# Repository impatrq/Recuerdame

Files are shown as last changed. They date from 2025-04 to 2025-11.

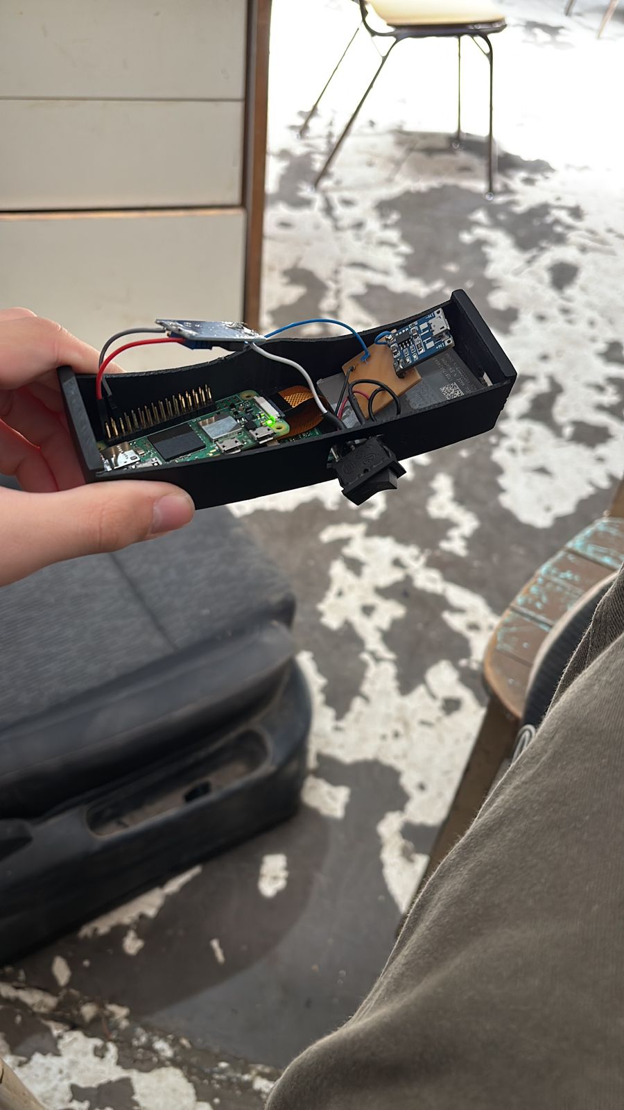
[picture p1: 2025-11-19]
Evidencia de trabajo 2025/Prueba de componentes 3er.jpeg

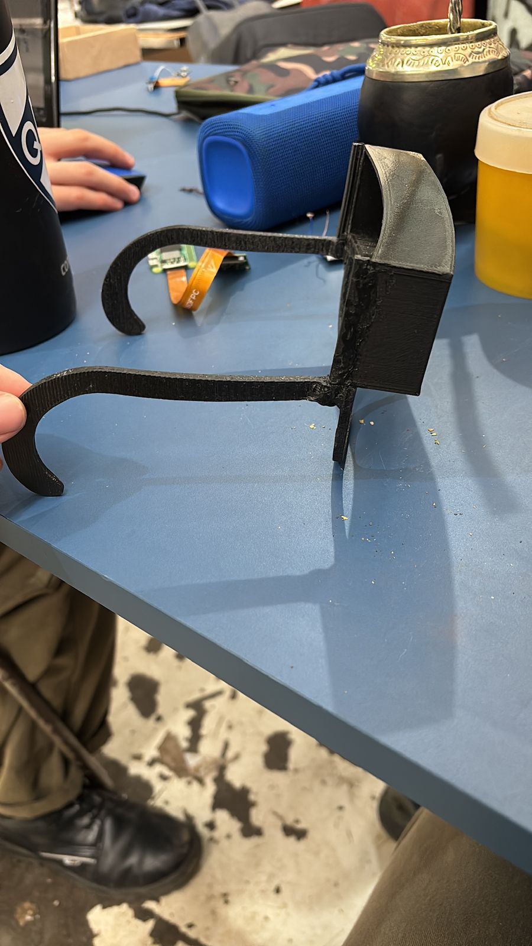
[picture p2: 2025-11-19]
Evidencia de trabajo 2025/Ensamblaje del segundo prototipo.jpeg

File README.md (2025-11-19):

🧠 Recuérdame – Sistema de Asistencia para Personas con Deterioro Cognitivo

Prototipo desarrollado con Raspberry Pi Zero 2, reconocimiento facial y WebApp propia para gestión de pacientes.

⸻

📌 Descripción del Proyecto

Recuérdame es un sistema diseñado para asistir a personas con deterioro cognitivo leve o moderado mediante:
	•	Reconocimiento facial en tiempo real
	•	Identificación por voz
	•	Registro y gestión de personas cercanas (familiares, amigos, cuidadores)
	•	Estadísticas de seguimiento cognitivo

El sistema funciona de manera autónoma, toma fotografías constantemente, detecta rostros y los compara con una base de datos alojada en MongoDB Atlas.
Al encontrar una coincidencia, anuncia por voz:

“Persona reconocida: Juan Pérez. Es su hijo.”

⸻

🚀 Tecnologías Utilizadas

Backend (Running en Raspberry Pi)
	•	Python 3
	•	Librería face_recognition
	•	PIL (Pillow)
	•	MongoDB Atlas mediante pymongo
	•	rpicam-apps (rpicam-still)
	•	espeak (síntesis de voz)

Frontend / WebApp
	•	HTML, CSS y JavaScript
	•	Express.js para servir la app
	•	MongoDB Atlas para almacenar pacientes
	•	Diseño mobile-first y estilo de app nativa

⸻

🧩 Cómo Funciona el Sistema
	1.	Los lentes capturan fotos cada 1 segundo.
	2.	El sistema detecta si hay un rostro presente.
	3.	Si se detecta una cara:
	•	Se genera su encoding (vector facial).
	•	Se compara con las codificaciones de la base de datos.
	4.	Si coincide con alguien registrado:
	•	Informa nombre y relación por voz.
	5.	Todo funciona de manera local, sin internet, una vez cargada la base.

⸻

📦 Instalación

1. Clonar el repositorio

		git clone https://github.com/tuusuario/Recuerdame.git
		cd Recuerdame

2. Instalar dependencias de Python

		pip install face_recognition pymongo pillow numpy

3. Instalar rpicam-apps

		sudo apt install rpicam-apps

4. Instalar espeak

		sudo apt install espeak

5. Configurar tu string de MongoDB en el archivo Python

		MONGODB_URI = "mongodb+srv://..."

⸻

▶️ Cómo Usar Recuérdame

1. Conectar el dispositivo a una red WiFi

2. Acceder a la terminal sin cable USB

(Gracias al sistema interno de acceso remoto)

3. Iniciar sesión con usuario y contraseña del equipo

4. Obtener la IP local

	hostname -I

5. En el navegador (misma red), entrar a la WebApp

	http://IP:5000

Ejemplo:

	192.168.0.15:5000

6. Registrar personas

En la sección Personas, se cargan:
	•	Nombre
	•	Relación
	•	Foto

Luego reiniciar Recuérdame para actualizar encodings.

7. Funcionamiento autónomo

Al iniciar:
	•	Procesa las fotos
	•	Crea las codificaciones
	•	Anuncia:
“Sistema Recuérdame listo para ayudarte.”
	•	Comienza a reconocer personas automáticamente.

8. Batería
	•	Carga por Micro-USB
	•	Aproximadamente 1 hora de carga = 3 horas de autonomía

⸻

📊 Estadísticas del Paciente

La WebApp calcula automáticamente:
	•	Cantidad de preguntas correctas / incorrectas / omitidas
	•	Último test realizado
	•	Tendencias semanales/mensuales
	•	Caídas significativas en orientación temporal o memoria
	•	Alertas visuales a familiares o profesionales

Incluye también una ficha rápida del paciente en la pantalla principal.
⸻

🔧 Arquitectura General

	[ Cámara Raspberry ] -> captura -> [ Procesador Pi Zero 2 ]
	        |                                     |
	        v                                     v
	[ face_recognition ] -> encodings -> [ Comparación con DB ]
	        |                                     |
	        v                                     v
	[ Identificación ] -----------------> [ Síntesis de voz ESpeak ]
	
⸻

🤝 Agradecimientos / Sponsors
	•	FADESA – Financió el 100% del proyecto.
	•	Proyecto Color – Diseño e impresión 3D de piezas.
	•	UADE – Prestó laboratorios y equipamiento.

⸻

🧑‍💻 Autores

    Carlos Gabri Krizak 
    Facundo Mendez
    Pedro Amenta

⸻

🏁 Estado del Proyecto

✔️ Prototipo funcional
✔️ Reconocimiento con ~80% de precisión
✔️ Base de datos integrada
✔️ WebApp operativa
⚙️ Mejoras futuras: optimizar rendimiento, integrar batería más grande.

⸻

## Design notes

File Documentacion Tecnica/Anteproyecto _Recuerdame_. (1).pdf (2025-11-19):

Escuela de Educación Técnica Nº7
Taller Regional Quilmes
Prácticas Profesionalizantes: Especialidad Aviónica

# Recuérdame

## Presentación de anteproyecto

### Recuerdame:

El nombre "Recuérdame" surge como una referencia directa a la función principal del proyecto: ayudar a personas con Alzheimer a recordar a sus seres queridos. Además, su fácil pronunciación y significado emotivo permiten una conexión inmediata con su propósito.

### Integrantes:

- AMENTA, Pedro.
- MENDEZ, Facundo.
- GABRI KRIZAK, Carlos.

### Objetivo del proyecto:

El objetivo de este proyecto es desarrollar unos lentes inteligentes diseñados para asistir a personas con la enfermedad de Alzheimer y a sus familiares o acompañantes en el proceso de afrontarla. Estos lentes incorporarán tecnología de reconocimiento facial y un sistema de audio que informará al usuario sobre la identidad y el parentesco de las personas a su alrededor.

Además, contarán con una funcionalidad interactiva que permitirá realizar preguntas diseñadas para ejercitar la capacidad cognitiva del paciente, como: "¿Cómo se llama su hijo?", "¿Tiene hijos?", "¿Cuántos?" o "¿Cuál era el nombre de sus padres?". Este método, altamente recomendado por profesionales, ayuda a estimular la memoria y reforzar la conexión con sus recuerdos.

Para evaluar la evolución del paciente, las respuestas a estas preguntas se registran y se convertirán en estadísticas visualizadas en gráficos dentro de la aplicación móvil. A través de esta app, los familiares y cuidadores podrán hacer un seguimiento del estado cognitivo del usuario y detectar posibles cambios en su capacidad de recordar información con el tiempo.

La finalidad de este proyecto es mejorar la calidad de vida de los pacientes, promover su autonomía y facilitar la comunicación con sus familiares y cuidadores, brindando una herramienta tecnológica accesible y eficaz.

### Utilidades de el proyecto:

El proyecto beneficiará directamente a pacientes con Alzheimer y a sus familiares, quienes podrán mantener una comunicación más efectiva y reducir la angustia generada por el desconocimiento. También podría ser de interés para centros de salud y organizaciones dedicadas a la atención de adultos mayores, mejorando la asistencia a personas con deterioro cognitivo.

### Descripción del funcionamiento:

Los lentes capturan la imagen de una persona mediante una cámara integrada. Esta imagen se envía a una Raspberry Pi Zero 2, donde se procesa con un sistema de reconocimiento facial. Si la persona es identificada en la base de datos, el sistema emite un mensaje de audio con su nombre y relación con el usuario.

Además de esta función principal, los lentes están diseñados para ayudar a estimular la memoria del paciente a través de preguntas interactivas. Estas preguntas pueden incluir: "¿Cómo se llama su hijo?", "¿Tiene hijos?", "¿Cuántos?", o "¿Cuál era el nombre de sus padres?". Este enfoque está respaldado por profesionales en el área de la salud, quienes recomiendan este tipo de ejercicios para mantener activa la capacidad cognitiva del usuario.

La interacción con el sistema se realizará mediante una aplicación vinculada, que permitirá ajustar parámetros como el volumen del audio, la frecuencia de las preguntas y la gestión de la base de datos de contactos. A largo plazo, se prevé la integración de tecnologías adicionales para mejorar la experiencia del usuario y optimizar el rendimiento del dispositivo.

### Análisis de factibilidad:

- Pedro Amenta: Redes sociales, diseño del logotipo, contacto con Sponsors, Encargado de Anteproyecto, investigación sobre la enfermedad.
- Problemática a resolver: Deberá definir una estrategia de marketing efectiva para aumentar la visibilidad del proyecto y atraer patrocinadores, garantizando que el mensaje llegue a las personas y organizaciones adecuadas.
- Segunda problemática a resolver: Tendrá que hacer un mensaje claro, conciso y convincente para la comunicación con marcas que puedan sponsorear distintas partes de nuestro proyecto.
- Tercera problemática a resolver: Será necesario capacitarse sobre la enfermedad de Alzheimer para adaptar el proyecto de la mejor manera posible a la vida de las personas que la padecen, garantizando que cuenten con todas las herramientas necesarias para mejorar su autonomía y calidad de vida.
- Carlos Gabri Krizak: Investigacion y Planificacion del proyecto, Desarrollo de App, Desarrollo del reconocimiento facial
- Problemática a resolver: Implementar un sistema de reconocimiento facial eficiente y de bajo consumo en la Raspberry Pi Zero 2, asegurando que funcione correctamente en distintas condiciones de iluminación y con diferentes ángulos de los rostros.

- Segunda problemática a resolver: Junto a su otro compañero hacer una capacitación y aumentar su conocimiento sobre la creación y desarrollo de aplicaciones.
- Facundo Mendez : Diseño de los lentes, Desarrollo de App
- Primera problemática a resolver: Diseñar un armazón de lentes ergonómico que pueda albergar los componentes electrónicos sin afectar la comodidad del usuario, garantizando al mismo tiempo que los sensores y la cámara funcionen correctamente.
- Segunda problemática a resolver: Junto a su otro compañero hacer una capacitación y aumentar su conocimiento sobre la creación y desarrollo de aplicaciones.

### Costo del proyecto:

- Raspberry Pi Zero 2: $34.000
- Cámara Módulo Raspberry CAM V1.3: $10.000
- Batería LiPo 1000mAh: $21.989

COSTO TOTAL ESTIPULADO: $65.989

### Análisis de costo/beneficio:

El costo de los componentes es relativamente accesible en comparación con el impacto positivo que puede generar el proyecto en la vida de los pacientes con Alzheimer y sus familias. Al ofrecer una solución tecnológica innovadora, se justifica la inversión en el desarrollo del prototipo, con posibilidades de financiamiento a través de entidades de salud o apoyo gubernamental.

Comparativa de soluciones a problemas actuales con soluciones que traería “Recuerdame”:

- Dificultad para reconocer a familiares y amigos debido al Alzheimer.
- Soluciones Actuales: Los cuidadores o familiares deben recordarles constantemente quiénes son las personas a su alrededor, lo que puede ser frustrante y no siempre efectivo. (Prácticamente no es una solución)
- Cómo lo resolvería "Recuérdame": Mediante el reconocimiento facial, los lentes identifican a las personas cercanas y proporcionan al usuario información auditiva sobre su identidad y parentesco.
- Pérdida de autonomía del paciente.
- Soluciones Actuales: Los pacientes suelen depender completamente de cuidadores para orientarse en su entorno social.
- Cómo lo resolvería "Recuérdame": Nuestro proyecto permite que los pacientes puedan interactuar de forma más independiente al recibir información sobre quienes los rodean sin necesidad de preguntar.
- Falta de estimulación cognitiva efectiva.
- Soluciones Actuales: Se utilizan ejercicios de memoria en papel o aplicaciones móviles que requieren que el usuario interactúe activamente con una pantalla.
- Cómo lo resolvería "Recuérdame": Los lentes integran un sistema de preguntas auditivas automatizadas para reforzar la memoria del paciente de manera más accesible y sin necesidad de manipular dispositivos.
- Falta de soluciones tecnológicas accesibles para pacientes con Alzheimer.
- Soluciones Actuales: Existen algunas apps de recordatorio, pero no hay dispositivos portátiles diseñados específicamente para asistir en tiempo real.
- Cómo lo resolvería "Recuérdame": Nuestro proyecto es un dispositivo wearable que proporciona ayuda en tiempo real sin necesidad de interacción manual.

### Diagrama en bloques del prototipo:

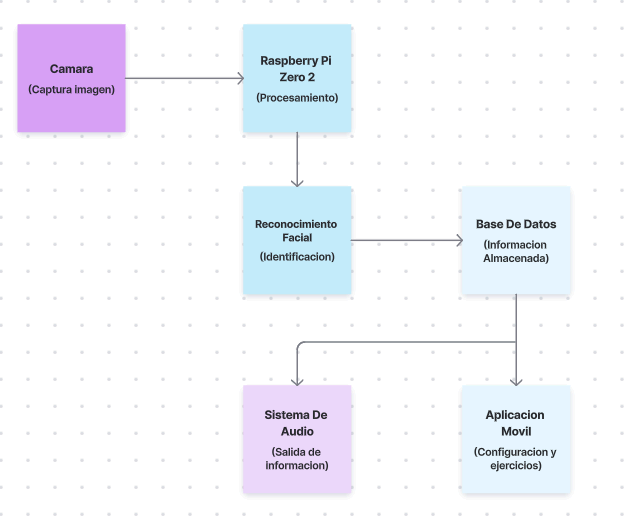
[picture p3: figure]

### Diagrama de tiempo de desarrollo:

- Etapa 1: Investigación y planificación (2 semanas, en proceso)
- Etapa 2: Marketing y propaganda (Tiempo indefinido, en proceso)
- Etapa 3: Desarrollo del sistema de reconocimiento facial (6 semanas)
- Etapa 4: Desarrollo de la aplicación móvil (6 semanas)
- Etapa 5: Diseño de los lentes (4 semanas)
- Etapa 6: Integración del sistema en los lentes (4 semanas)
- Etapa 7: Pruebas y ajustes finales (Tiempo indefinido)

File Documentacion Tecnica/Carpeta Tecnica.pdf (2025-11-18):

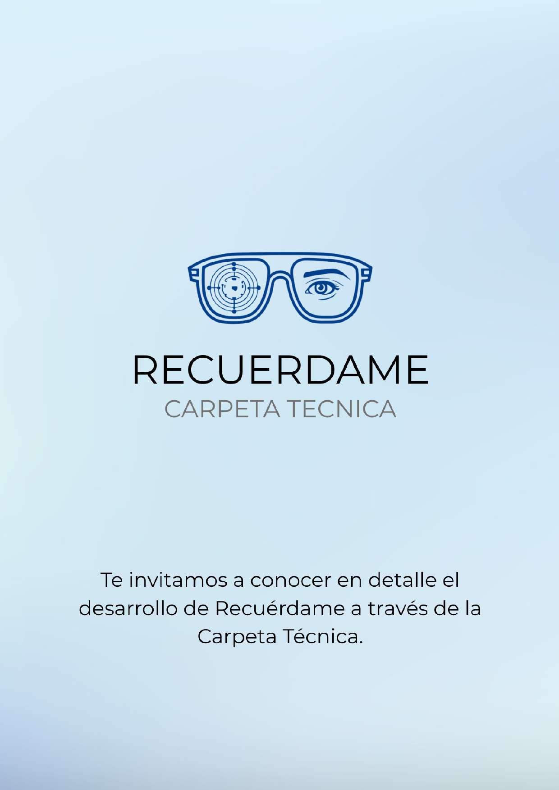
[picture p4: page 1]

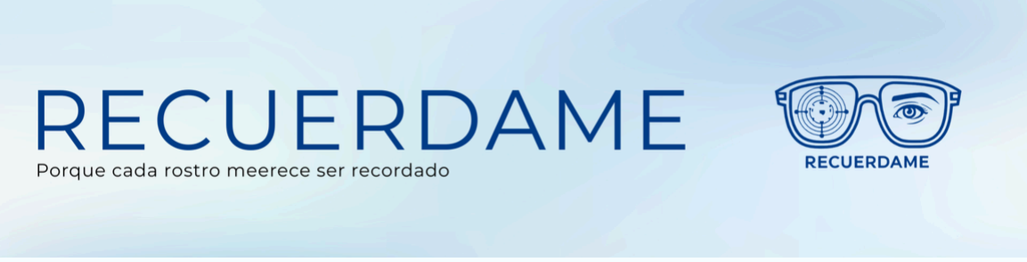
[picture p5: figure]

# Carpeta Técnica – Proyecto Recuérdame

1. ¿Qué es Recuérdame?
2. ¿Cómo Nace Recuérdame?
3. Objetivos
a. Objetivo general
b. Objetivos específicos
4. Hardware
a. Componentes utilizados
b. Modelo 3D y Estructura
5. Software
a. Sistema de reconocimiento facial (lentes inteligentes)
b. WebApp “Recuérdame App”
c. Pagina Web informativa
6. Resultados y pruebas
a. Pruebas del sistema de reconocimiento facial
b. Pruebas de conexión con la base de datos y la WebApp
c. Resultados generales
7. Agradecimientos
8. Conclusión

## ¿Qué es “Recuérdame”?

Recuérdame es un sistema de asistencia inteligente diseñado para ayudar a personas con pérdida de memoria o dificultades cognitivas.
El proyecto combina hardware y software para reconocer rostros y brindar información relevante sobre las personas que el usuario ve, ayudándolo a mantener su autonomía y mejorar su calidad de vida.

El sistema está compuesto por unos lentes inteligentes, desarrollados con una Raspberry Pi Zero 2, una cámara y un módulo de audio Bluetooth, que permiten capturar imágenes del entorno y procesarlas mediante reconocimiento facial.

Además, cuenta con una WebApp, donde familiares o profesionales pueden registrar personas, realizar preguntas cognitivas diarias y monitorear el estado cognitivo del paciente a través de estadísticas automáticas.

El objetivo principal de Recuérdame es ofrecer una herramienta accesible y práctica para acompañar a quienes padecen enfermedades neurodegenerativas como el Alzheimer, combinando tecnología e inclusión social.

## ¿Cómo nace Recuérdame?

El proyecto Recuérdame nació a partir de una experiencia personal de uno de los integrantes. A comienzos del año, mientras Carlos hablaba con su papá sobre su bisabuela (quien padecía demencia) recordó cómo, en un mismo día, le preguntaba varias veces “¿Quién sos vos?”. Cada vez que el le respondía, ella le contestaba “Ya sabía, te estaba cargando”, intentando disimular la vergüenza que le generaba no recordar.

Esa situación lo marcó profundamente y lo hizo pensar en lo difícil que debe ser convivir con la pérdida de la memoria, tanto para quien la sufre como para sus familiares y acompañantes. Recuérdame nace de ese recuerdo, con la idea de crear una herramienta que brinde apoyo y contención mediante la tecnología.

## Objetivos

### Objetivo general

Desarrollar un sistema de lentes inteligentes capaz de asistir a personas con pérdida de memoria mediante el reconocimiento facial y una plataforma web de seguimiento cognitivo, promoviendo la autonomía, la seguridad y el bienestar del usuario.

### Objetivos específicos

Implementar un sistema de reconocimiento facial utilizando la cámara de la Raspberry Pi Zero 2.

Diseñar y fabricar una estructura ergonómica mediante modelos 3D para integrar los componentes electrónicos en unos lentes funcionales.
Desarrollar una WebApp que permita registrar personas, realizar preguntas cognitivas diarias y almacenar resultados en una base de datos.
Establecer una comunicación entre los lentes y la aplicación para el intercambio de información (alertas, estadísticas, etc.).
Generar estadísticas automáticas que evalúen el rendimiento cognitivo para el médico de cabecera.
Garantizar que el sistema sea accesible, intuitivo y adaptable a las necesidades de cada usuario.

## Hardware

### Componentes utilizados

El sistema Recuérdame está construido a partir de distintos módulos electrónicos que trabajan en conjunto para permitir el reconocimiento facial y la comunicación con la aplicación.
A continuación, se detallan los principales componentes utilizados:

Raspberry Pi Zero 2 W: microcomputadora principal encargada del procesamiento, reconocimiento facial y de ejecutar la App.
Cámara para Raspberry Pi: permite capturar imágenes del entorno para realizar el reconocimiento de rostros.
Módulo TP4056: utilizado para la carga de la batería de litio, brindando protección contra sobrecarga y sobredescarga.
Step-up booster (DC-DC): eleva el voltaje de la batería (3.7 V) a 5 V, necesarios para alimentar la Raspberry Pi.
Batería recargable de litio: fuente de energía principal de los lentes.
Cableado y conectores: empleados para interconectar los distintos módulos de manera segura y compacta.

Conexiones: todos los componentes fueron integrados mediante soldaduras y cables flexibles para minimizar el espacio ocupado dentro de la estructura de los lentes.

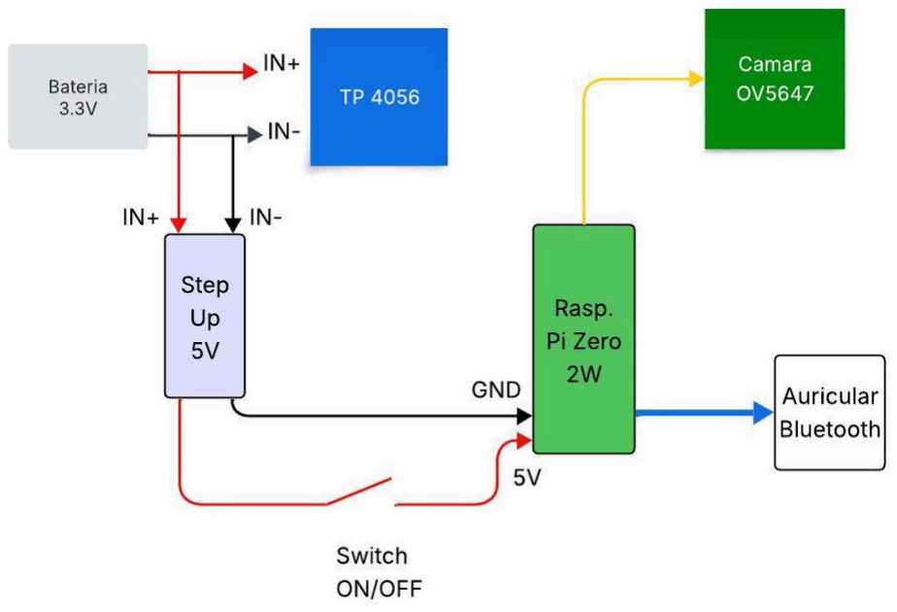
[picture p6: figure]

### Modelos 3D y estructura

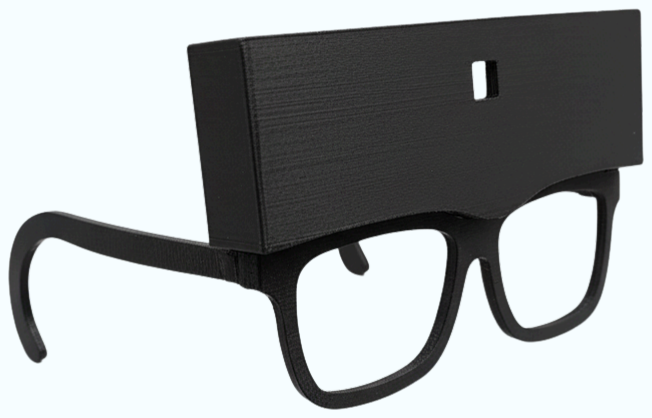
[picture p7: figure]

Para integrar todos los componentes, se diseñó un modelo 3D de los lentes inteligentes, adaptado para alojar la Raspberry Pi, la cámara y los módulos electrónicos sin afectar la comodidad del usuario.

El diseño fue realizado con software de modelado 3D (AutoCAD) y luego impreso con impresora 3D utilizando material PLA.
El objetivo del diseño fue lograr una estructura ergonómica, liviana y estética, que permita el uso prolongado sin incomodidad, manteniendo la funcionalidad del sistema.

## Software

El software de Recuérdame integra distintos componentes que trabajan en conjunto para conectar los lentes inteligentes con la WebApp de seguimiento cognitivo.
El sistema fue desarrollado para funcionar en un entorno de bajo consumo de recursos, utilizando modelos preentrenados optimizados para la Raspberry Pi Zero 2, y una arquitectura cliente-servidor que permite la comunicación entre el hardware y la base de datos en la nube.

### Sistema de reconocimiento facial (lentes inteligentes)

Debido a las limitaciones de hardware de la Raspberry Pi Zero 2, se optó por no utilizar librerías pesadas como OpenCV.
En su lugar, el reconocimiento facial se basa en tres modelos preentrenados livianos, cada uno con una tarea específica:

Modelo de detección de rostros: identifica la posición de las caras dentro del fotograma. Modelo de reconocimiento facial: obtiene los rasgos característicos (embeddings) de cada rostro detectado.
Modelo de comparación: compara los embeddings del rostro actual con los almacenados en la base de datos local o remota, determinando si corresponde a una persona conocida.

### WebApp “Recuérdame App”

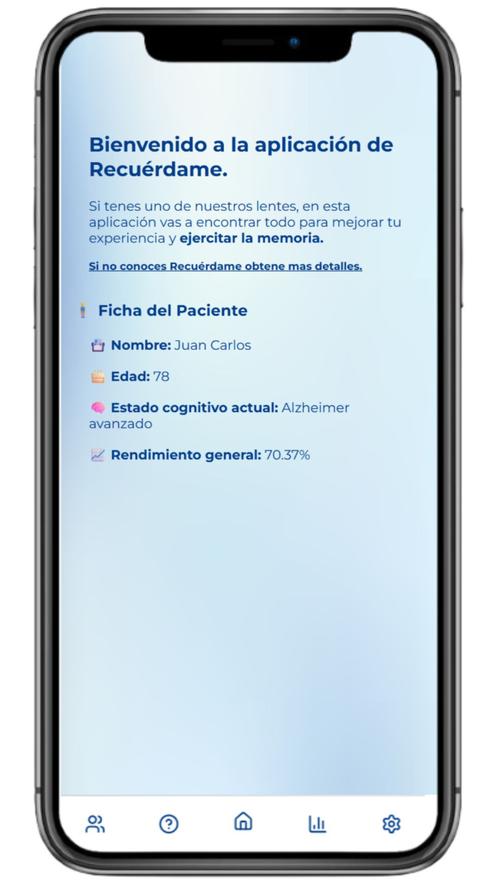
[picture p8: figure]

La WebApp fue desarrollada desde cero con el objetivo de ofrecer una interfaz intuitiva y moderna, optimizada para dispositivos móviles.
Está implementada con las siguientes tecnologías:

Frontend: HTML, CSS y JavaScript (con diseño tipo app nativa).
Backend: Node.js con Express.
Base de datos: MongoDB Atlas. Servidor: ejecutado en el puerto 5000, sirviendo contenido estático desde la
carpeta public.

La aplicación permite a familiares o profesionales:

Registrar personas, asociarles fotos y descripciones.
Realizar preguntas cognitivas diarias, clasificadas por tipo (memoria, orientación temporal, orientación espacial, lenguaje y cálculo).
Registrar las respuestas como “Correcta” o “Incorrecta”.
Generar estadísticas automáticas semanales y mensuales, mostrando patrones de rendimiento.
Alertar automáticamente si se detecta una baja significativa en el rendimiento del paciente.

### Interfaz del usuario en la App

La WebApp cuenta con una interfaz de navegación simple, pensada para adultos mayores y cuidadores.
Las principales vistas son:

Pantalla de inicio: muestra la ficha rápida del paciente (nombre, edad, estado cognitivo, último test y rendimiento general).
Vista Personas: lista de personas registradas con opción para agregar, editar o eliminar. Vista Preguntas: donde se realizan las preguntas cognitivas diarias.
Vista Estadísticas: presenta gráficos del progreso y alertas automáticas sobre posibles deterioros.

### Página web informativa

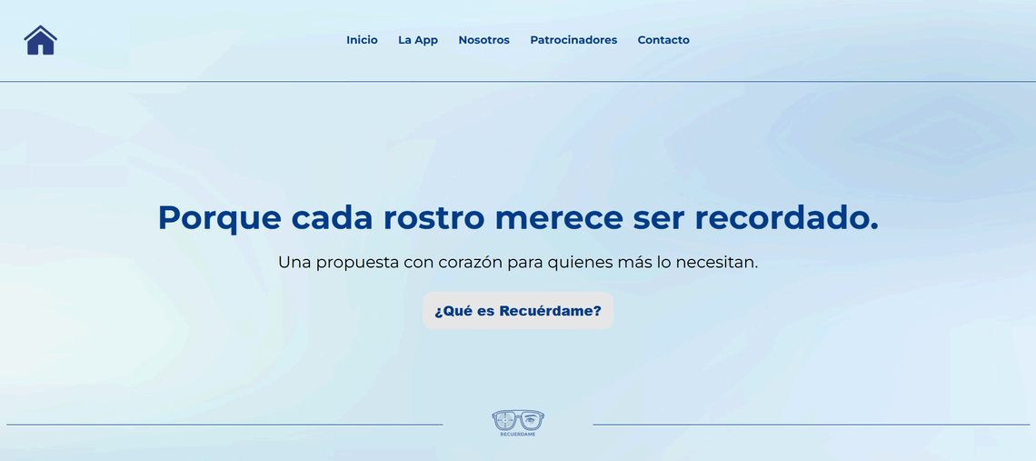
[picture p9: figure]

El proyecto cuenta con una página web informativa alojada en el dominio propio https://recuerdamecpf.lat. (https://recuerdamecpf.lat/?utm_source=chatgpt.com)
Fue desarrollada por el grupo utilizando HTML, CSS y JavaScript, con un diseño moderno, simple y adaptable a distintos dispositivos.

La web tiene como objetivo presentar el proyecto, explicar su funcionamiento de forma general y mostrar información sobre el equipo desarrollador.
Su función principal es divulgar y representar al proyecto en la muestra escolar y en eventos, sirviendo como carta de presentación digital.

## Resultados y pruebas

### Pruebas del sistema de reconocimiento facial

El sistema de reconocimiento fue probado con los tres integrantes del equipo de desarrollo, utilizando los modelos preentrenados de detección, reconocimiento y comparación facial. Durante las pruebas, el sistema logró identificar correctamente los rostros en aproximadamente un 80 % de los intentos, mostrando un buen nivel de precisión considerando las limitaciones de hardware de la Raspberry Pi Zero 2.

El funcionamiento es autónomo, sin necesidad de conexión a una computadora externa, lo cual demuestra la viabilidad del diseño para su uso independiente en los lentes inteligentes.

### Pruebas de conexión con la base de datos y la WebApp

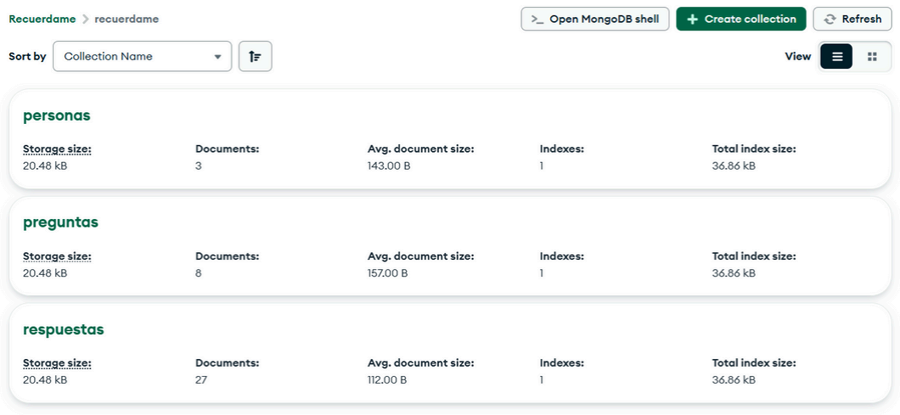
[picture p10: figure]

Se realizaron pruebas exitosas de conexión con la base de datos MongoDB Atlas, verificando el correcto envío, almacenamiento y lectura de datos a través del servidor Node.js / Express.
La WebApp permitió registrar usuarios, responder preguntas cognitivas y visualizar los resultados en tiempo real, confirmando el correcto funcionamiento del flujo completo de datos entre el dispositivo, el servidor y la base
de datos.

### Resultados generales

En conjunto, las pruebas realizadas demostraron que el sistema es funcional, estable y cumple con los objetivos propuestos:

Detecta y reconoce rostros de manera autónoma.
Se comunica correctamente con la base de datos.
Presenta una interfaz web informativa y una WebApp funcional.

## Agradecimientos

Queremos agradecer a las instituciones y organizaciones que hicieron posible el desarrollo de Recuérdame:

FADESA (Fundación Argentina para el Desarrollo de la Salud), por financiar el 100 % del proyecto y confiar en nuestra propuesta desde el inicio.
Proyecto Color, por su colaboración en el diseño y la impresión de las piezas en 3D, aportando precisión y calidad al prototipo final.
UADE (Universidad Argentina de la Empresa), por su buena predisposición y por permitirnos utilizar sus laboratorios para realizar pruebas y ensayos del sistema.

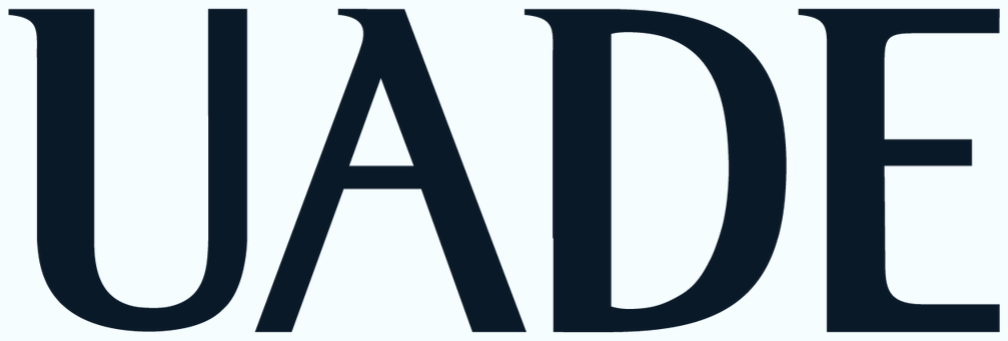
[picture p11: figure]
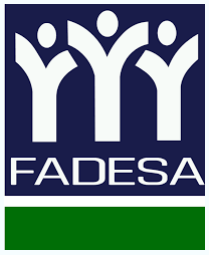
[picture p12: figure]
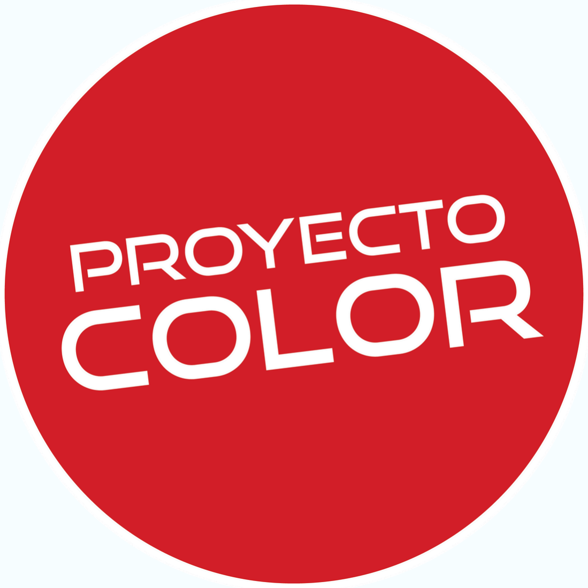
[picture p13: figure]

## Conclusión

El desarrollo de Recuérdame permitió aplicar conocimientos de electrónica, programación y diseño 3D en un proyecto con impacto social real.
El sistema logró cumplir con los objetivos propuestos, demostrando que es posible integrar hardware de bajo costo para mejorar la calidad de vida de las personas con pérdida de memoria.

El trabajo reflejó el esfuerzo y compromiso del grupo en todas sus etapas (desde la idea inicial hasta las pruebas finales), combinando innovación tecnológica y empatía humana.

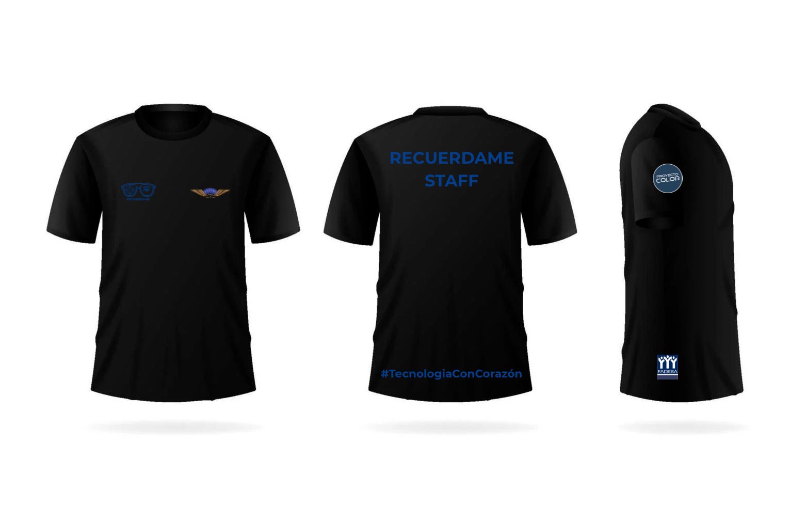
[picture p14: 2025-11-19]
Evidencia de trabajo 2025/Diseño Remeras.jpeg

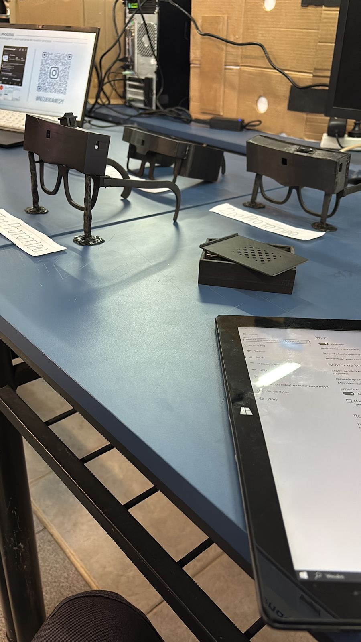
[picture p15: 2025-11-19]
Evidencia de trabajo 2025/Stand Oniet.jpeg

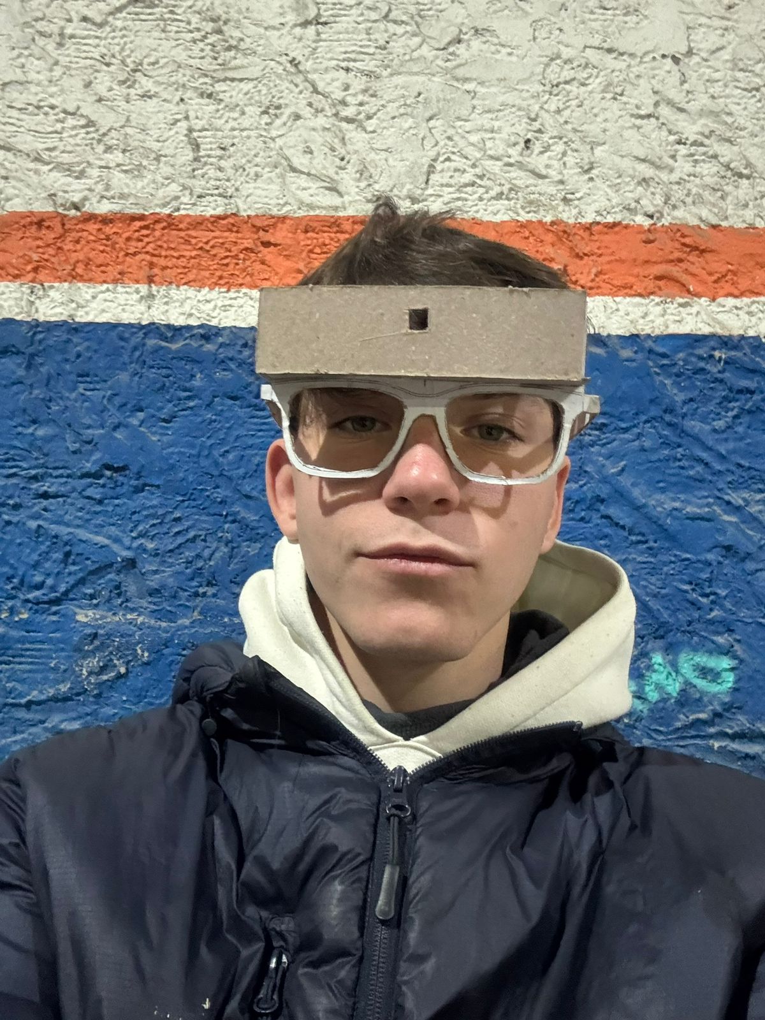
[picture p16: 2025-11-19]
Evidencia de trabajo 2025/Carton.jpeg

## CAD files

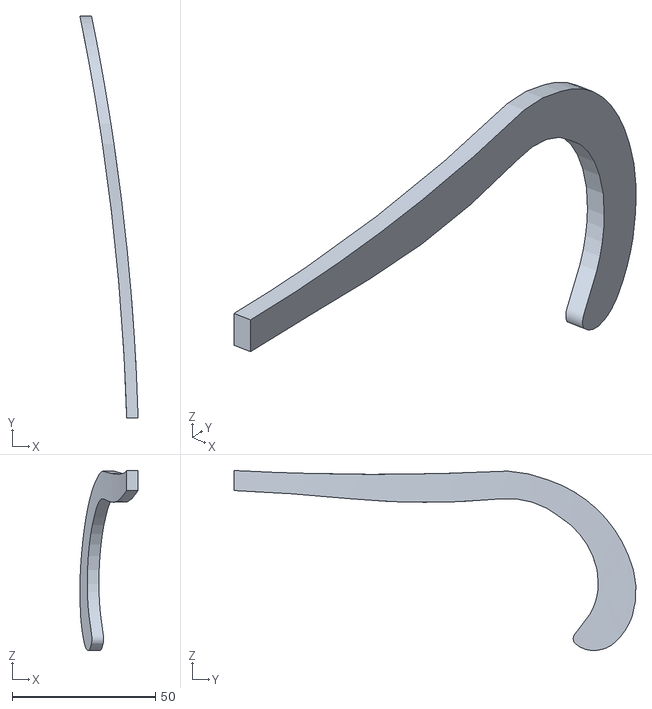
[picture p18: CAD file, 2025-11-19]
Prototipos/PataIzquierda4.stl
20.3 x 140.1 x 62.8

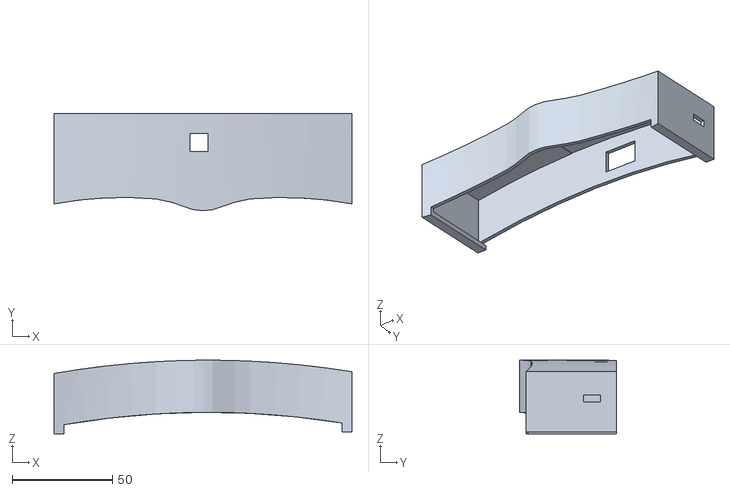
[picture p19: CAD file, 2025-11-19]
Prototipos/Componentes5.stl
148.5 x 48.2 x 36.7

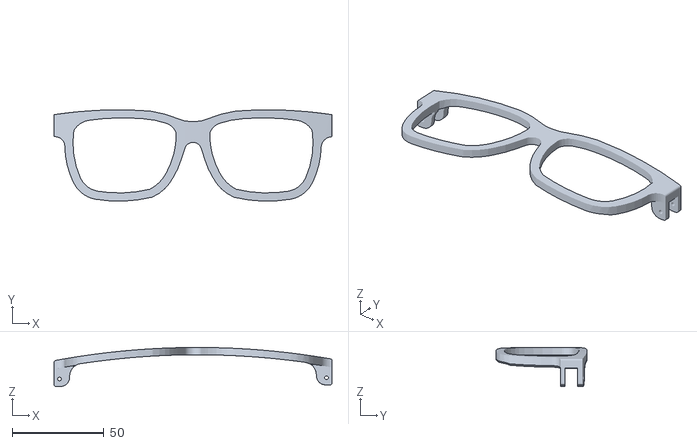
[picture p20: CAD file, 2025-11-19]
Prototipos/Marco6.stl
151.5 x 49.7 x 21.3

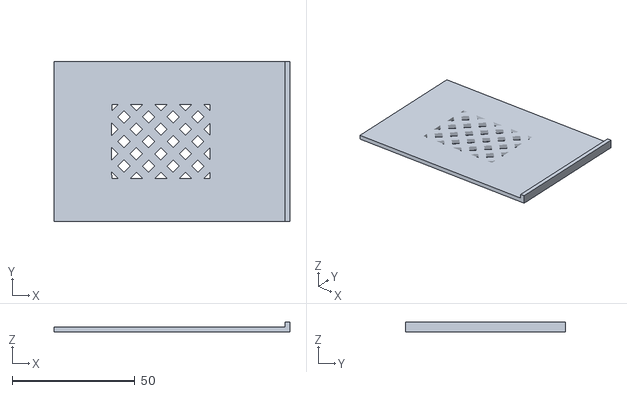
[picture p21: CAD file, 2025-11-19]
Prototipos/TapaRejilla1.stl
96.0 x 65.0 x 4.00

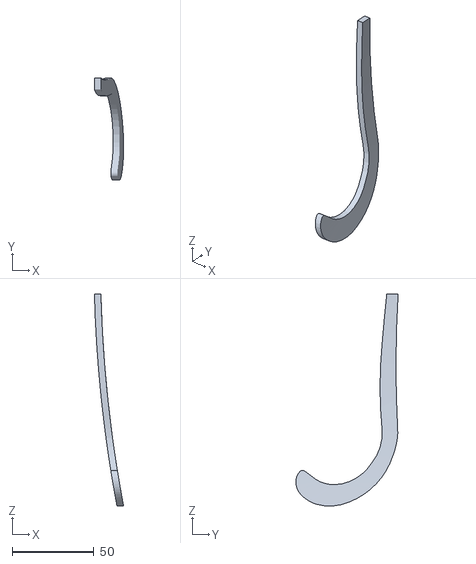
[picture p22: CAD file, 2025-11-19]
Prototipos/PataDerecha1.stl
17.9 x 62.8 x 130.1

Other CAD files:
Prototipos/REJILLA1.stl
Prototipos/PataIzquierda1.stl
Prototipos/SegundoPrototipoGit.dwg
Prototipos/PrimerPrototipoGit.dwg
Prototipos/TercerPrototipoGit.dwg

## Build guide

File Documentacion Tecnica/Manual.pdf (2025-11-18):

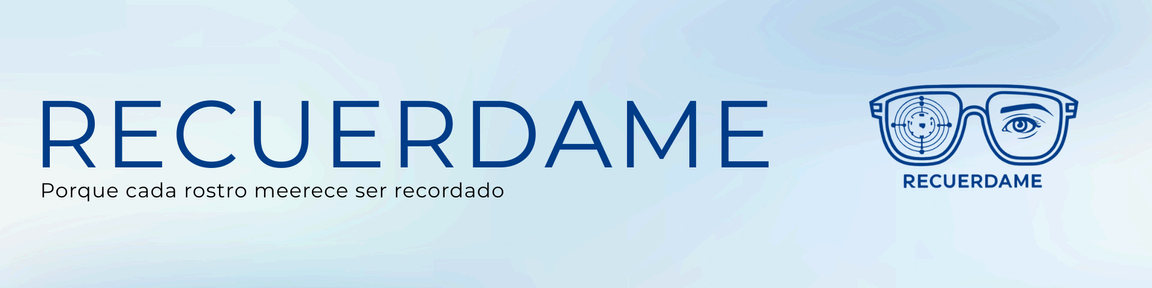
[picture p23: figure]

# Manual de Usuario – Recuérdame

Este manual explica cómo encender, configurar y utilizar el prototipo de Recuérdame, junto con las funciones de registro, estadísticas, preguntas cognitivas y juegos incluidos en el sistema.

# 1. Puesta en marcha del dispositivo

1. Encender Recuérdame conectándolo mediante el cable Micro-USB a cualquier cargador o batería externa.
2. Esperar a que el sistema inicie por completo.
3. No es necesario conectarlo por USB a una PC: el dispositivo permite acceder a la terminal desde la misma red WiFi.
4. Desde una computadora o celular conectado a la misma red, iniciar una conexión SSH utilizando el nombre del dispositivo.
5. Para obtener la dirección IP, ejecutar en la terminal:

hostname -I

# 2. Acceso a la aplicación web

1. En cualquier dispositivo conectado a la misma red WiFi, abrir un navegador.
a. En la barra de direcciones escribir:
[IP obtenida]:5000

( Ejemplo: 192.168.0.1:5000)

2. Se abrirá la WebApp de Recuérdame, donde se administran personas, estadísticas y ejercicios cognitivos.

# 3. Registro de personas

1. Acceder a la sección “Personas” dentro de la WebApp.
2. Completar los datos requeridos: nombre, relación con el paciente y fotografía.
3. Guardar el registro.
4. Reiniciar Recuérdame para actualizar la base de datos interna del sistema de reconocimiento.

# 4. Funcionamiento del reconocimiento facial

- Después de aproximadamente 1 minuto, el dispositivo emite mediante el dispositivo Bluetooth que el usuario elija (auriculares, parlante, etc.) el mensaje: “Sistema Recuérdame listo para ayudarte.”
- A partir de ese momento, el sistema queda activo.
- Cuando la cámara detecta un rostro registrado, Recuérdame anuncia:
- Quién es la persona
- Qué relación tiene con el paciente

# 5. Preguntas cognitivas diarias

La WebApp incluye un sistema de evaluación cognitiva con preguntas diarias divididas en categorías:

- Preguntas Personales
- Preguntas Actuales
- Preguntas de espacio

## ¿Cómo usarlas?

1. Entrar a la sección “Preguntas”.
2. Realizar cada pregunta al paciente.
3. Registrar la respuesta como:
- Bien
- Mal
4. Todas las respuestas quedan guardadas automáticamente en la base de datos. Estas respuestas se utilizan luego para generar estadísticas y tendencias cognitivas.

# 6. Estadísticas del paciente

La WebApp genera estadísticas automáticas, útiles para familiares y profesionales.

## ¿Qué información muestra?

- Rendimiento semanal y mensual según tipo de pregunta
- Promedio general de aciertos
- Gráficos de progreso por categoría cognitiva

## ¿Para qué sirven?

Permiten:

- Hacer seguimiento del estado cognitivo del paciente
- Detectar señales tempranas de deterioro
- Evaluar si un tratamiento está funcionando
- Compartir informes con médicos o acompañantes terapéuticos

La ficha del paciente en la pantalla de inicio muestra:

- Nombre
- Edad
- Estado cognitivo general
- Fecha del último test
- Rendimiento promedio

Los datos se actualizan automáticamente según las respuestas registradas.

# 8. Carga del dispositivo

- Se carga mediante Micro-USB.
- Tiempo de carga: aproximadamente 1 hora.
- Autonomía: alrededor de 3 horas de uso continuo.

Puede utilizarse mientras se carga.

# 9. Recomendaciones de uso

- Mantener el prototipo y el dispositivo desde el que se accede a la WebApp en la misma red WiFi.
- Reiniciar siempre después de agregar nuevas personas.
- Asegurar que la cámara esté despejada y limpia.
- Cargar el dispositivo antes de cada sesión de uso.

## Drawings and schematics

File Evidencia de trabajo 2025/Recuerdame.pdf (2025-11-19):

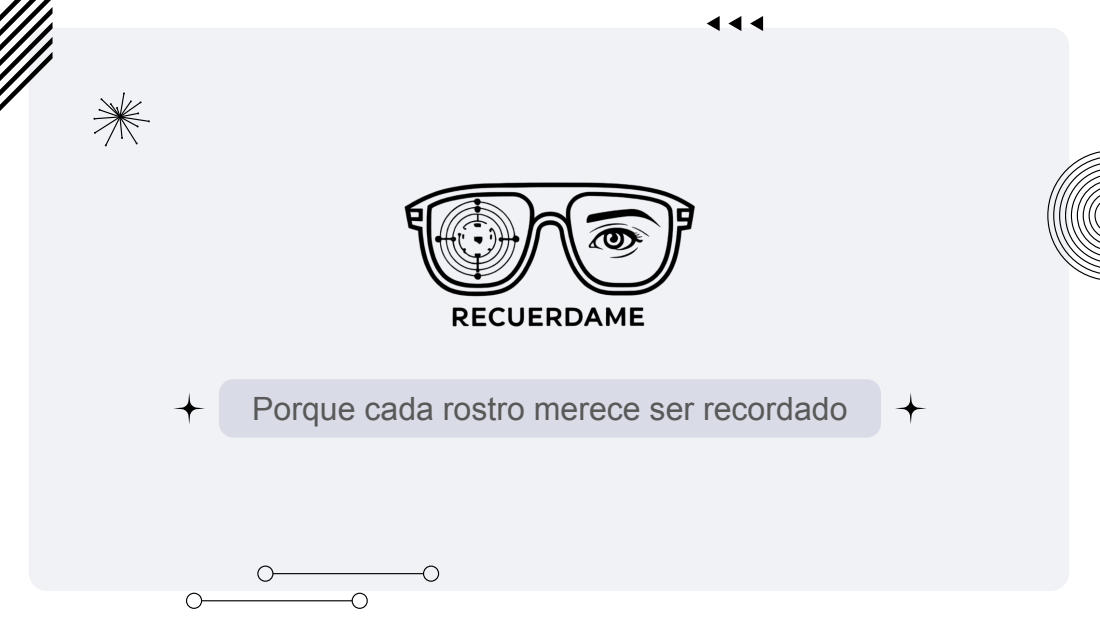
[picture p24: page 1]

Porque cada rostro merece ser recordado

# ¿Que problema venimos a resolver?

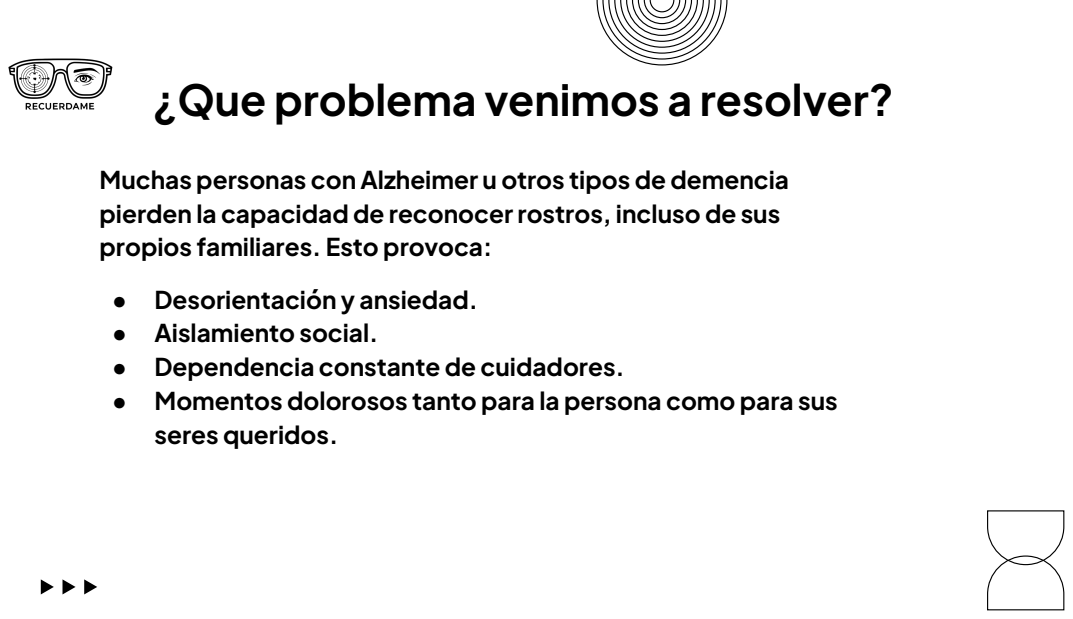
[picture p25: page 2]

Muchas personas con Alzheimer u otros tipos de demencia
pierden la capacidad de reconocer rostros, incluso de sus
propios familiares. Esto provoca:
● Desorientación y ansiedad.
● Aislamiento social.
● Dependencia constante de cuidadores.
● Momentos dolorosos tanto para la persona como para sus
seres queridos.

# ¿Que tan comun es el Alzheimer?

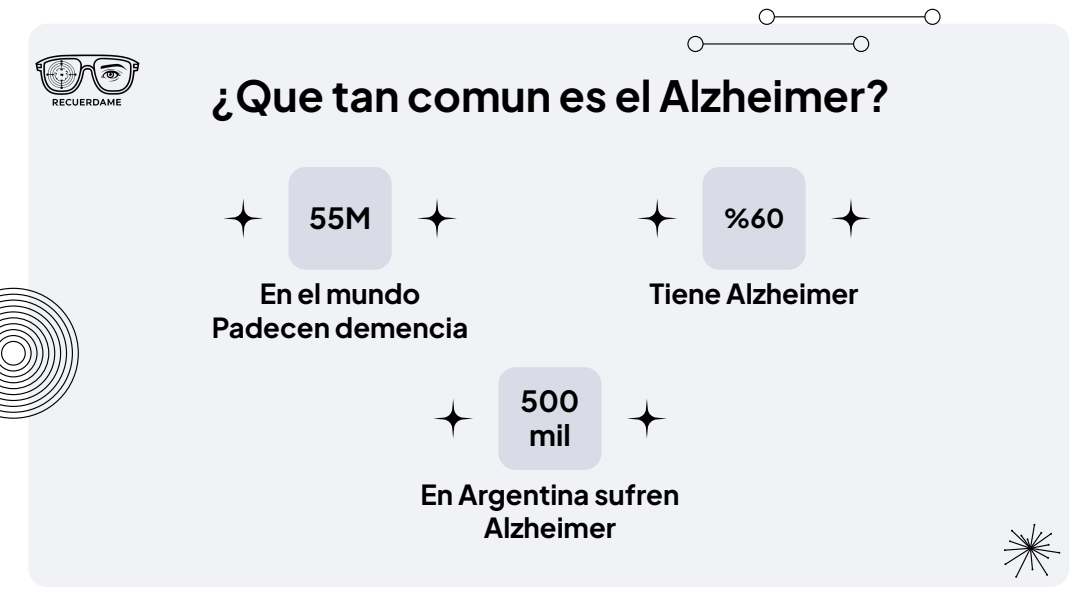
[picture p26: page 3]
Tiene Alzheimer; 500 mil

En el mundo
Padecen demencia

En Argentina sufren
Alzheimer

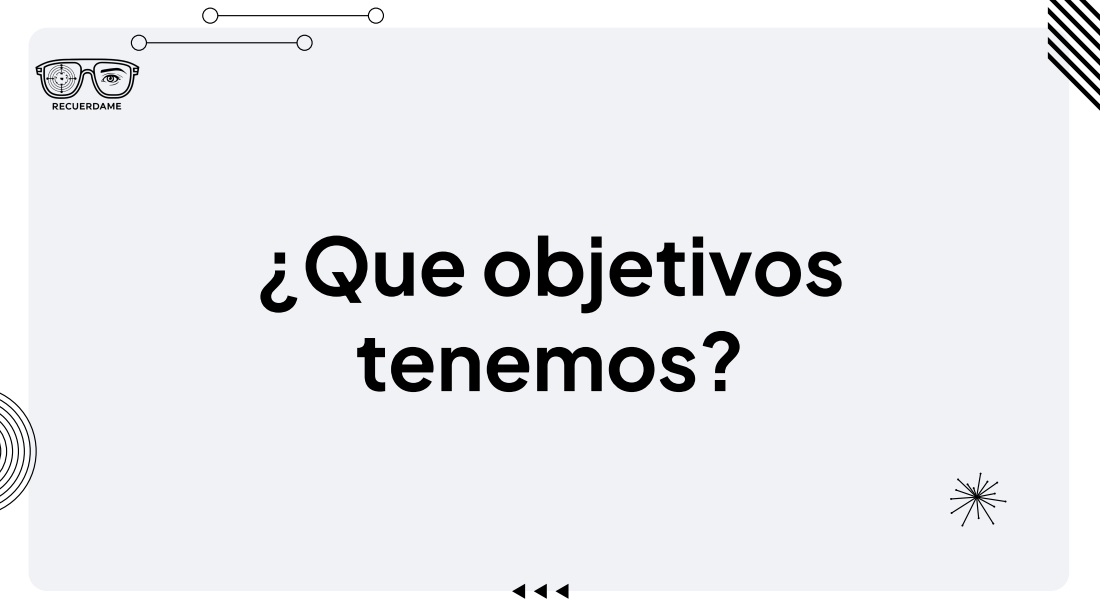
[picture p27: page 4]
¿Que objetivos tenemos?

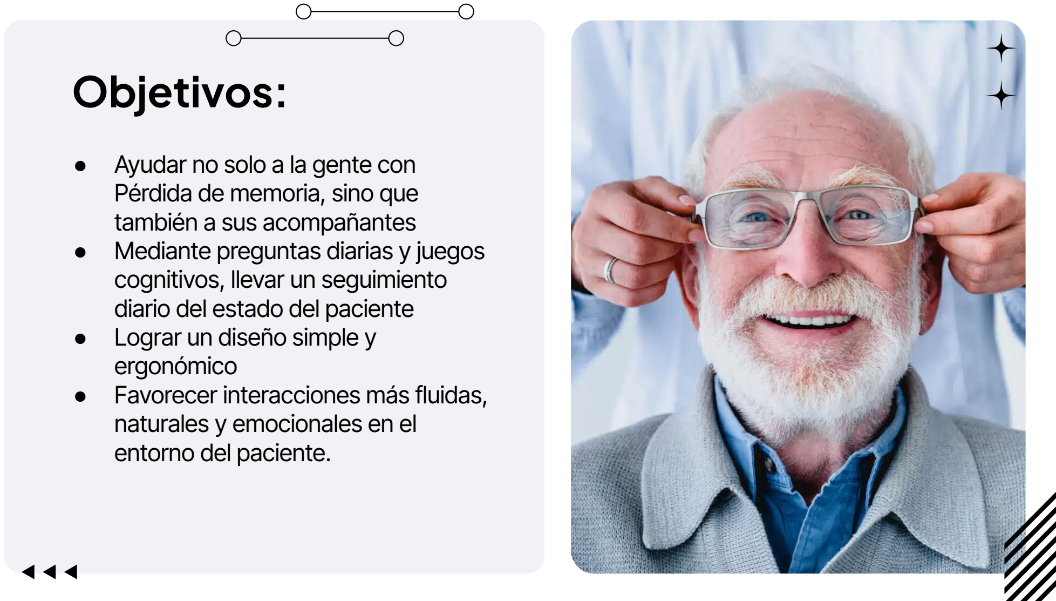
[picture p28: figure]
Objetivos:; ● Ayudar no solo a la gente con Pérdida de memoria, sino que también a sus acompañantes ● Mediante preguntas diarias y juegos cognitivos, llevar un seguimiento diario del estado del paciente ● Lograr un diseño simple y ergonómico ● Favorecer interacciones más fluidas, naturales y emocionales en el entorno del paciente.
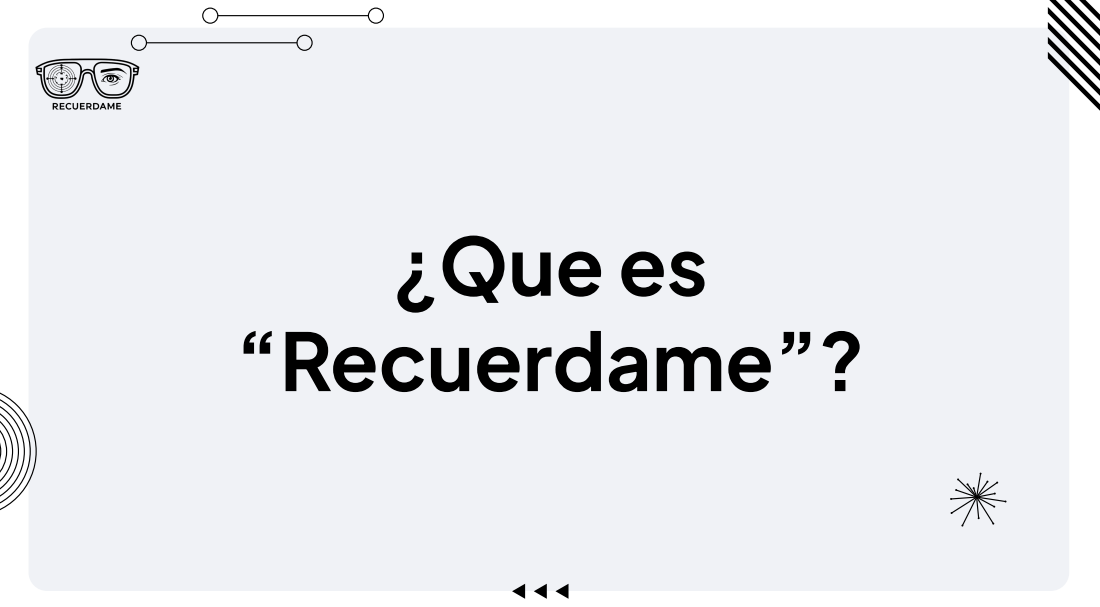
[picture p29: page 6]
¿Que es “Recuerdame”?

## “Recuérdame” es un sistema compuesto por unos lentes

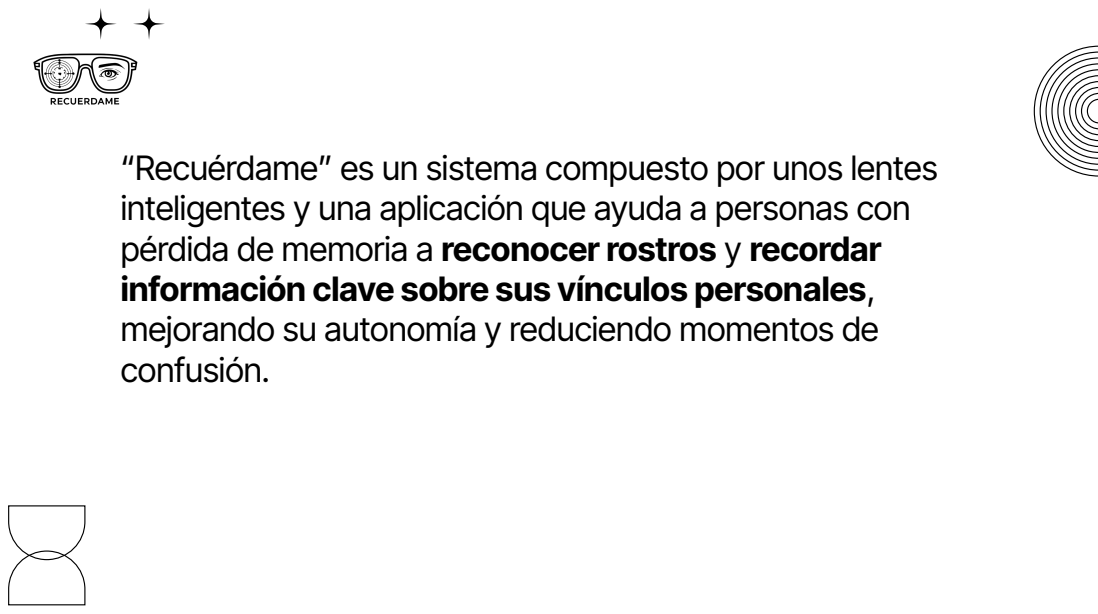
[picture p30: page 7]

inteligentes y una aplicación que ayuda a personas con
pérdida de memoria a reconocer rostros y recordar
información clave sobre sus vínculos personales,
mejorando su autonomía y reduciendo momentos de
confusión.

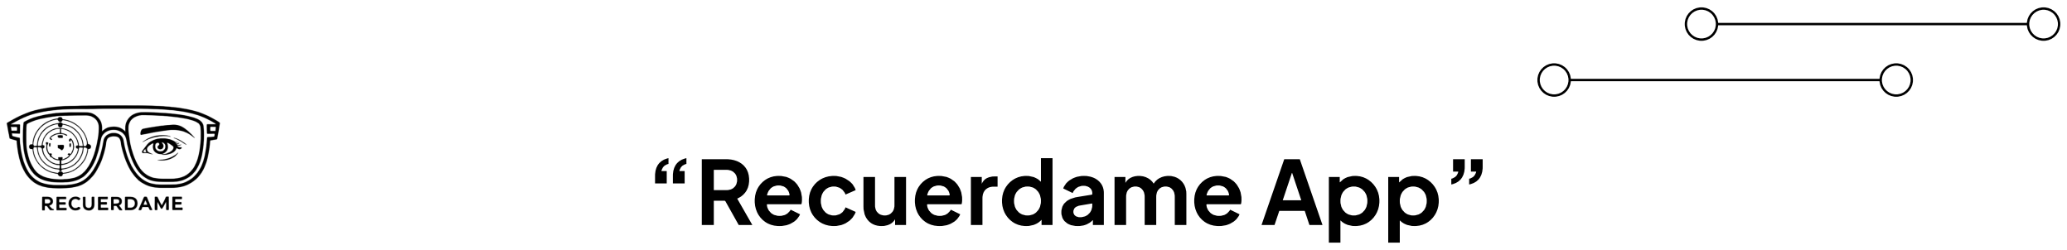
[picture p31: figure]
“Recuerdame App”

Cargar fotos y descripciones para que el sistema pueda
identificarlas y describirlas por audio.

La app realiza preguntas
simples al paciente para
ejercitar la memoria.

Seguimiento cognitivo
Compara las respuestas del día con una referencia y
registra la respuesta

Permite que cuidadores o
familiares gestionen la
información del paciente de forma remota y sencilla.
Registrar Personas | Preguntas diarias | Control

# Funcionamiento de los Lentes

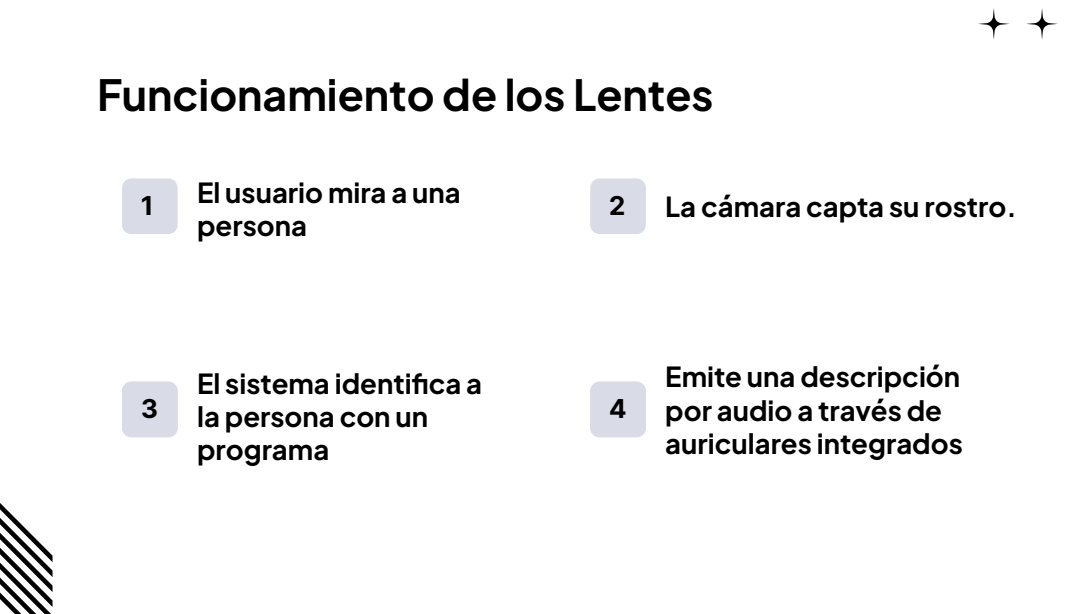
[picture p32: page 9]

El usuario mira a una
persona

La cámara capta su rostro.

El sistema identifica a
la persona con un
programa

Emite una descripción
por audio a través de
auriculares integrados

# Componentes

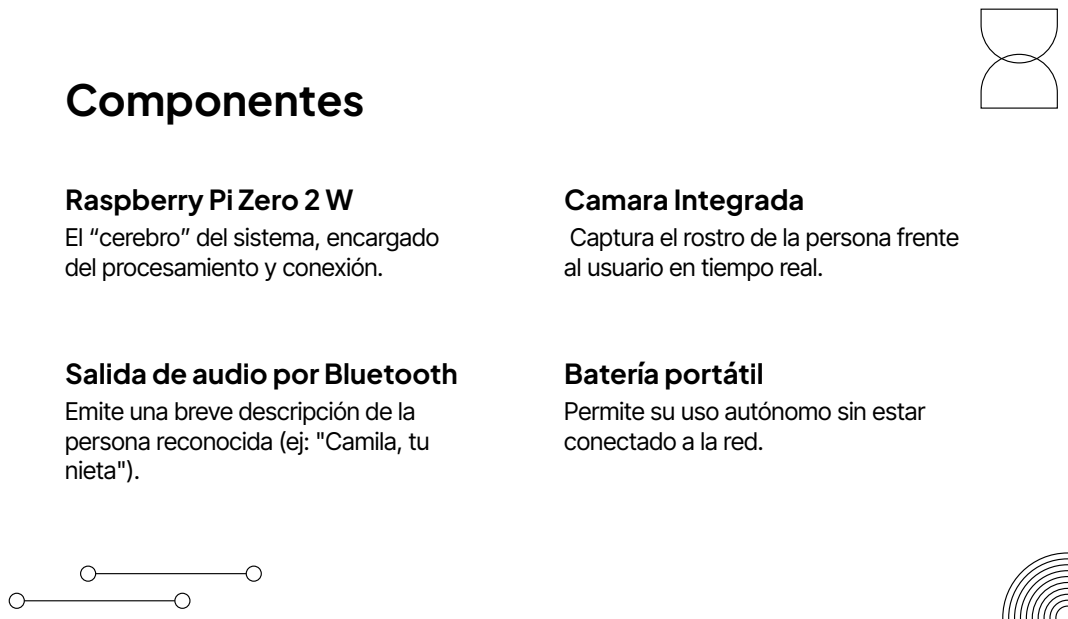
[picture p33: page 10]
Raspberry Pi Zero 2 W; Camara Integrada; Salida de audio por Bluetooth; Batería portátil

El “cerebro” del sistema, encargado
del procesamiento y conexión.

Captura el rostro de la persona frente
al usuario en tiempo real.

Emite una breve descripción de la
persona reconocida (ej: "Camila, tu
nieta").

Permite su uso autónomo sin estar
conectado a la red.

$40.000

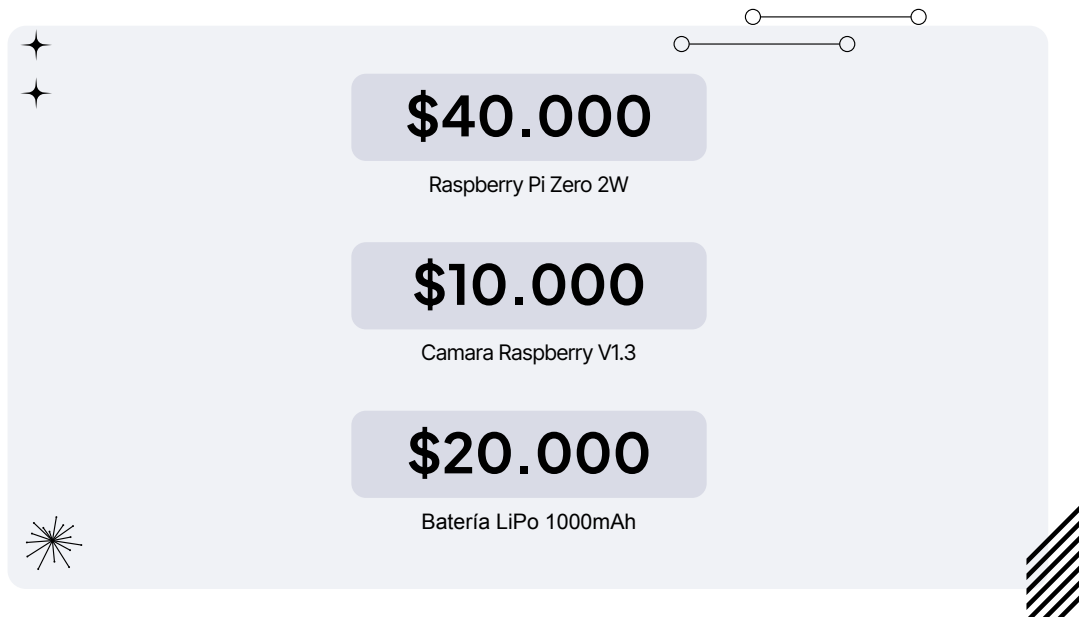
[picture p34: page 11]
Camara Raspberry V1.3; Batería LiPo 1000mAh

Raspberry Pi Zero 2W

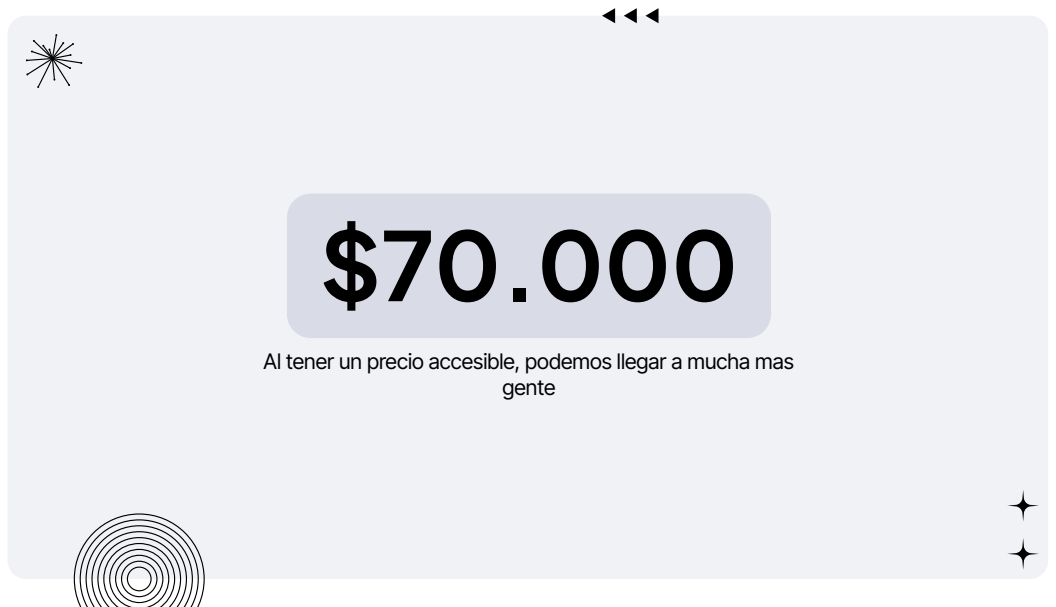
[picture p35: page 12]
gente

Al tener un precio accesible, podemos llegar a mucha mas

# Estado del proyecto


Idea y arquitectura definidas

Desarrollo en curso de la App

Prototipo físico en armado

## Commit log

2025-11-19 Patas 1
    [PataDerecha1.stl, PataIzquierda1.stl]
2025-11-19 Lente 1
    [Lente1.stl]
2025-11-19 Primer intento de prototipo con rejilla
    [REJILLA1.stl, TapaRejilla1.stl]
2025-11-19 Modelo 4
    [Componentes5.stl, Marco6.stl, PataIzquierda4.stl]
2025-11-19 Presentacion creada para la charla con FADESA
2025-11-19 Carta que hacia realidad a FADESA como sponsor
2025-11-19 Diseño en cartón para probar medidas del segundo
2025-11-19 Ensamblamos el segundo prototipo de los lentes
2025-11-19 Prueba 3er prototipo
    Hicimos una prueba para ver si entraban todos los componentes y ver si era funcional
2025-11-19 Diseño de la Remera para la muestra
2025-11-19 Rename Stand Oniet.jpeg to Evidencia de trabajo 2025/Stand Oniet.jpeg
2025-11-19 Rename Diseño Remeras.jpeg to Evidencia de trabajo 2025/Diseño Remeras.jpeg
2025-11-19 Rename Prueba de componentes 3er.jpeg to Evidencia de trabajo 2025/Prueba de componentes 3er.jpeg
